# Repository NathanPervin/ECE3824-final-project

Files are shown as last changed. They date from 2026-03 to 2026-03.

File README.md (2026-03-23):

# CO2 Monitor
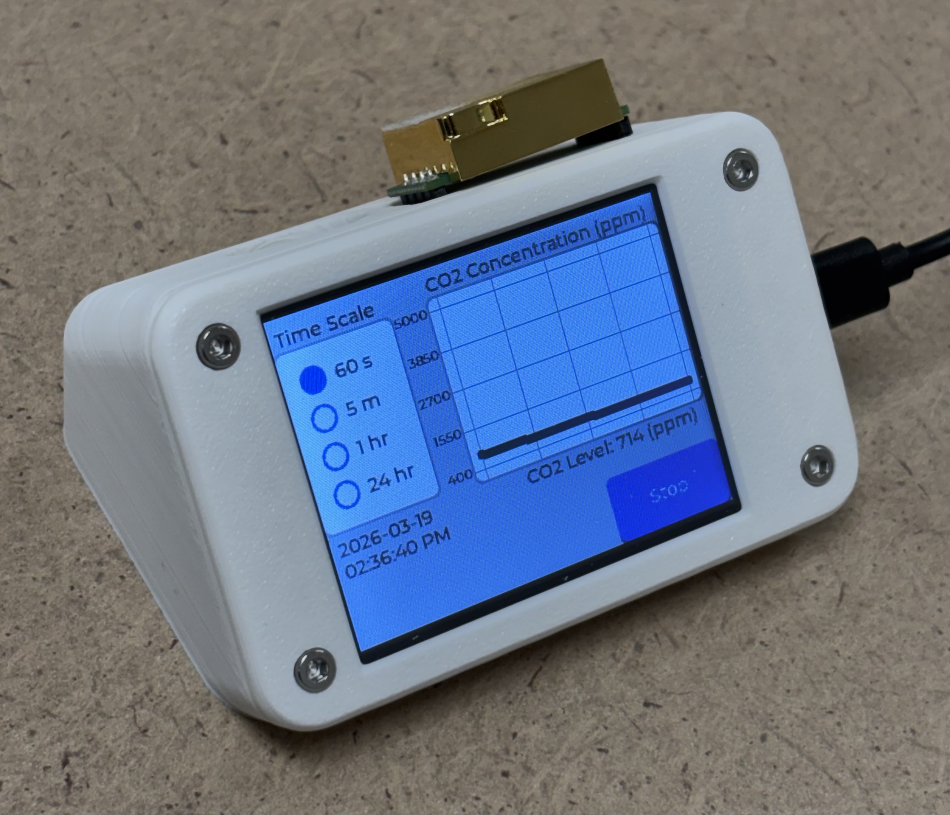
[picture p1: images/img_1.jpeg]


### Description
An ESP-32 device that monitors the CO2 level in the room and sends the infomation to a database in the cloud. A website will display the data.

### Impact
[Studies](https://www.sciencedirect.com/science/article/pii/S036013232300358X) have shown that short-term exposure to high levels of CO2 can reduce cognitive performance and negatively impact learning. Therefore, it is important to be ensure that CO2 levels remain low in an academic setting.

### Components
MH-Z19C CO2 Sensor ([more info](https://www.winsen-sensor.com/d/files/infrared-gas-sensor/mh-z19c-pins-type-co2-manual-ver1_0.pdf)) \
[by EC Buying](https://www.amazon.com/EC-Buying-Monitoring-Concentration-Detection/dp/B0CRKH5XVX)

ESP32 Cheap Yellow Display ([more info](https://www.lcdwiki.com/2.8inch_ESP32-32E_Display))\
[by Hosyond](https://www.amazon.com/gp/product/B0D92C9MMH)

3.7V LiPo Battery\
[by MakerHawk](https://www.amazon.com/gp/aw/d/B0D7MC714N)

### Features
* Screen automatically sleeps after 5 minutes of inactivity
* 1100 mAh battery with charging via the USB-C port (~6hr wireless battery life)
* Zero the CO2 sensor to 400 ppm by depressing the button for 7 seconds (only do this when outdoors)

### Dependencies
* Django for web app, API endpoint, and PostgreSQL database
* LVGL for ESP-32 GUI
* TFT_eSPI
* XPT2046_Touchscreen

### Web Hosting
* AWS EC2 for Django application
* AWS RDS for PostgreSQL

### Data Collection and Upload
Data will be in the following format:
```JSON
{"mode":"ambient","building":"COE","room_number":306,"unix_timestamp":1678886400,"CO2_ppm":750}
{"mode":"ambient","building":"COE","room_number":306,"unix_timestamp":1678886401,"CO2_ppm":760}
```
Samples will be taken every 1 second. The timestamp will be updated after each data POST request to keep the timestamps accurate over long periods of time. POST requests will be made every 5 minutes to reduce power usage and live data is already displayed on the CYD. A PostgreSQL database hosted in the cloud will be used to store the data.

### Pinout
| Pin | Use |
|-----|-----|
| IO35 | PWM for CO2 Sensor |
| 5V (UART PORT) | Vin for CO2 Sensor |
| GND | GND for CO2 Sensor |
| GND | GND for button -> CO2 Sensor HD Pin |

### CAD
Modified [ghfisanotti's CYD Case on Thingiverse](https://www.thingiverse.com/thing:7047135), licensed under CC BY-SA 3.0. See CAD folder in this repo for the STL and STEP files. 

### Required Parts and Assembly
* 1x ESP-32 CYD
* 1x MH-Z19C CO2 Sensor
* 1x 3.7 V Lipo w/ JST 1.25mm connector *optional
* 2x 1.25mm 4-pin JST to Dupont connectors
* 1x CYD_LID (3D printed)
* 1x CYD_BASE (3D printed)
* 4x M3 heat-set inserts
* 4x M3x8 bolts
* 1x [push button](https://www.amazon.com/Waterproof-Momentary-Button-Switch-Colors/dp/B07F24Y1TB) *optional, for zeroing the sensor
* 1x 5-pin female pin header *optional, for securing the sensor to the base

The 5-pin female pin header is secured by melting the plastic around it with a soldering iron. On the female pin header that the MH-Z19C's HD pin will plug into, solder a wire (this will connect to one pin of the button). Connect the other pin of the button to a GND pin on the CYD.

### Stretch Goals
* Dark Mode for ESP-32
* Handle http failure codes: handle extending batch size for POST failure, reattempt POST some number of times before clearing the buffer to avoid overflow. 
* ESP-32 timezone configuration for displayed time
* add more than just wifi connection errors to esp-32 error handler

### Data Visualization
* User should be able to search by building, room number, time (range, date)
* User should be able to see the most recent data in a plot (with the number of minutes since last data upload)
* User should be able to modify the parameters of the displayed plot (ex. time scale)
* Code should include a room score so the user can search for the rooms with the highest and lowest CO2 levels
* user should be able to search for a building and see all room numbers listed and the number of sessions/ ambients for each, also the room scores should be visable here.
* user should be able to select a room number from the above list and see a list of sessions, selecting one brings up a plot with the data.

### Temporary development notes
#### Tutorials 
[GUI Configs](https://randomnerdtutorials.com/lvgl-cheap-yellow-display-esp32-2432s028r) \
[LVGL Widgets Docs](https://docs.lvgl.io/master/widgets/)

#### TODO
* stop button logs whatever data is cached and goes back to start screen
* display elapsed time also if in session mode
* set building and room number to 'debug' when value is not given (so it can be filtered out in database)
* check if the plot can just be refreshed without loading new buffer (with flag for refresh without time scale change)
* first 1-2 mins make plot line blue to indicate sensor warming up
* make sure not to call get unix time twice when logging data (use same reference for displaying the time and logging data)
* stop button should disconnect wifi
* dont get unix time from load_buffers every time it is called, get unix time when making a post, increment the existing unix time from load_buffers instead since it is called once per second (create new variable for increment amount in case data logging interval changes in future)
* maybe use a finer time scale than seconds
* create stylus holder loop next to usb-c port due to issue where the stylus can fall into the enclosure
* write documentation for buffer max sizes for secrets.h.example, include the max building and room sizes, max JSON lines, etc.
* check if its currently on by checking if the most recent timestamp is less than 5 mins, indicate that its the live data and not the most recent session/ambient
* chart on first page should default to the most recent session, searching for a second would replace that plot with the data the user wants

* sessions in dashboard/views.py only returns UTC time regardless of user's timezone

minor bug fixes
* duration shows 4mins 59 secs instead of 5 mins for single upload (check if this error will accumulate)

#### Info
EC2 instance Django server running on:
http://107.23.179.9:8000/

Create virtual environment
```bash
python -m venv venv
```

activate the environment
```bash
source venv/bin/activate
```

Install PostgreSQL
```bash
sudo apt install postgresql postgresql-contrib
```

```bash
pip install -r requirements.txt
```

Create a .env inside of CO2 Dashboard, add the secrets, then run the server:
```bash
nohup python3 manage.py runserver 0.0.0.0:8000 &
```

Add the ip address to the allowed host list in setting.py.

stop old application
```bash
pkill -f "manage.py runserver"
```

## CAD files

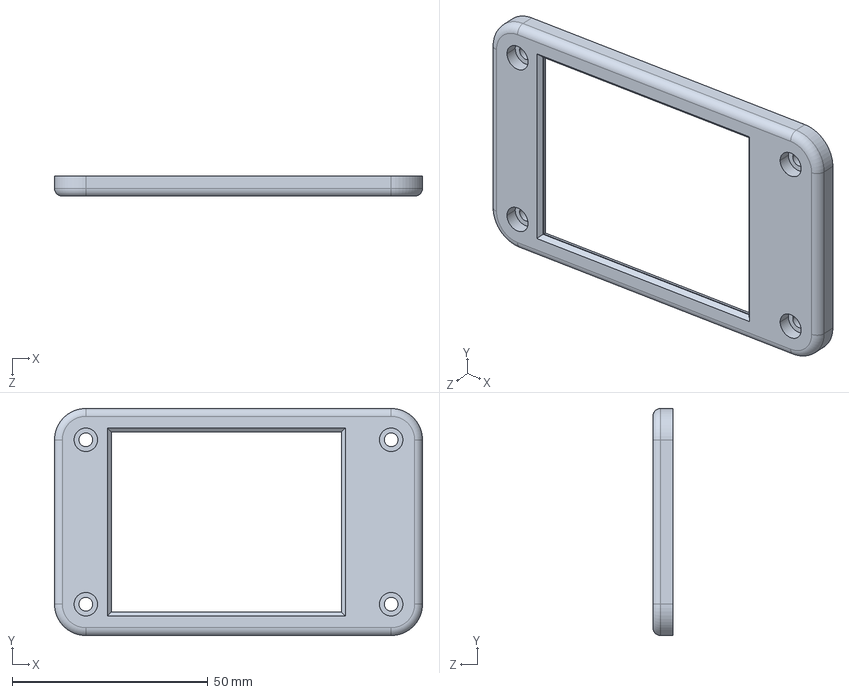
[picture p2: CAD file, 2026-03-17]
CAD/CYD_LID.STEP
94.0 x 58.0 x 5.20 mm

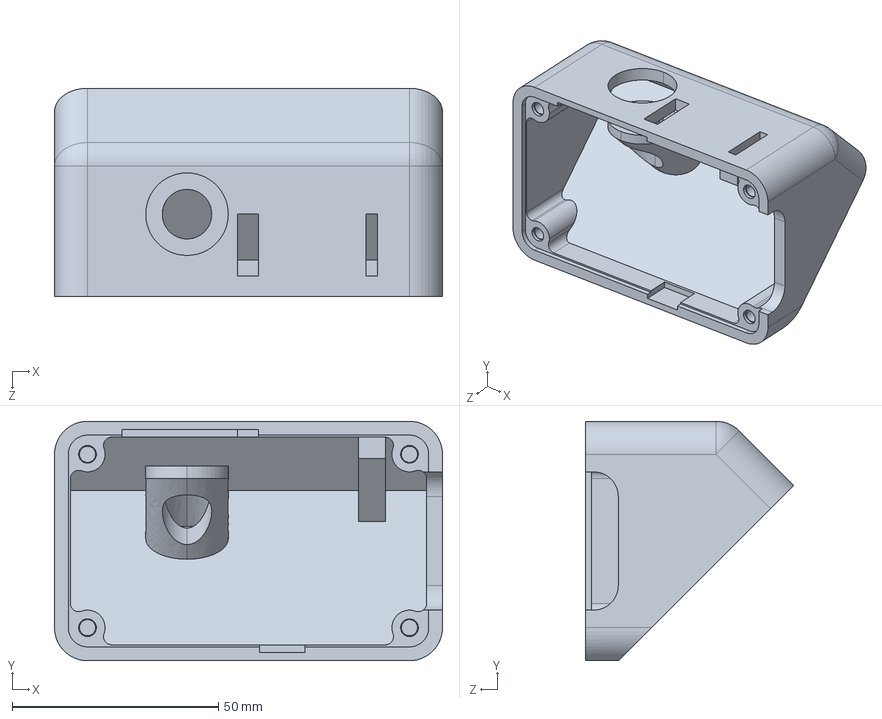
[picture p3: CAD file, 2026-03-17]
CAD/CYD_BASE.STEP
94.0 x 58.0 x 50.5 mm

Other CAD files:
CAD/CYD_BASE.STL
CAD/CYD_LID.STL

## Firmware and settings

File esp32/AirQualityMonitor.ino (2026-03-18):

// GUI:
// Configuration files and base code from: https://randomnerdtutorials.com/lvgl-cheap-yellow-display-esp32-2432s028r
// LVGL documentation: https://docs.lvgl.io/

// includes for GUI
#include <lvgl.h>
#include <TFT_eSPI.h>
#include <XPT2046_Touchscreen.h>

// includes for WIFI
#include <WiFi.h>
#include <time.h>
#include <secrets.h>

/*
    GUI Variables
*/
// Touchscreen pins
#define XPT2046_IRQ 36   // T_IRQ
#define XPT2046_MOSI 32  // T_DIN
#define XPT2046_MISO 39  // T_OUT
#define XPT2046_CLK 25   // T_CLK
#define XPT2046_CS 33    // T_CS

#define TFT_BL 21 // backlight

SPIClass touchscreenSPI = SPIClass(VSPI);
XPT2046_Touchscreen touchscreen(XPT2046_CS, XPT2046_IRQ);

#define SCREEN_WIDTH 240
#define SCREEN_HEIGHT 320

// Touchscreen coordinates: (x, y) and pressure (z)
int x, y, z;

#define DRAW_BUF_SIZE (SCREEN_WIDTH * SCREEN_HEIGHT / 10 * (LV_COLOR_DEPTH / 8))
uint32_t draw_buf[DRAW_BUF_SIZE / 4];

const char* top_text = "Air Quality Monitor";
const char* enter_building_text = "Building";
const char* enter_room_number_text = "Room Number";
const char* ambient_text = "Ambient";
const char* session_text = "Session";
const char* CO2_plot_title = "CO2 Concentration (ppm)";
const char* time_scale_text = "Time Scale";

bool is_ambient = true; // default value is to record as an ambient, if false, mode is session

static lv_obj_t* start_screen;
static lv_obj_t* recording_screen;

static lv_obj_t * ta1; // text area for the building input
static lv_obj_t * ta2; // text area for the room input

#define MAX_INPUT_TEXT_LENGTH 50
char building_text[MAX_INPUT_TEXT_LENGTH];
char room_text[MAX_INPUT_TEXT_LENGTH];

static lv_obj_t * chart;
static lv_chart_series_t * ser;

// the width of the x axis, in seconds 
static short int time_scale = 60; 

// determines how many point will be displayed at once,
const short int number_plot_points = 60; 
const short int CO2_plot_rate = 1000; // ms
static short int CO2_min = 400; // ppm
static short int CO2_max = 5000; // ppm

static lv_style_t style_radio;
static lv_style_t style_radio_chk;

const char* time_scales[] = {
  "60 s",
  "5 m",
  "1 hr",
  "24 hr",
  NULL
};

typedef enum {
  t_60s,
  t_5mins,
  t_1hr,
  t_24hrs
} TimeScale;

TimeScale current_time_scale = t_60s;

const int screen_sleep_after_time = 300000; // ms, 5 mins

lv_obj_t * CO2_level_label;
char CO2_level_text[30];

lv_obj_t * time_label;
char time_text[32];

lv_obj_t * error_label;
char error_text[32];

/*
//  CO2 Sensor Variables
*/
#define CO2_PWM_PIN 35

volatile unsigned long previous_low_start = 0;  // us
volatile unsigned long previous_high_start = 0; //us
volatile unsigned long TL = 0; // us
volatile unsigned long TH = 0; // us

const short int CO2_log_rate = 1000; // ms

/*
    WIFI Variables
*/
const char* ntpServer = "pool.ntp.org";
const long gmtOffset_sec = -18000;   // EST
const int daylightOffset_sec = 3600;  // 1 hour for daylight saving
bool wifi_initialized = false;
//int last_wifi_init_attempt = 0; // seconds since last initialization attempt
//const int attempt_wifi_init_every = 120; // interval for time between wifi attempts to be initalized

unsigned long last_wifi_init_attempt = 0; // timestamp of last attempt
const unsigned long attempt_wifi_init_every = 120000; // 2 minutes in ms

/*
    System Variables
*/
// buffers that will store the last 60 points
// which are an average of the available time intervals
static int32_t buffer_60secs[number_plot_points];
static int32_t buffer_5min[number_plot_points];
static int32_t buffer_1hr[number_plot_points];
static int32_t buffer_24hrs[number_plot_points];

// store the index where the next value should be placed
int i_60secs = 0;
int i_5mins = 0;
int i_1hr = 0;
int i_24hrs = 0;

// variables to find the average CO2 ppm over an interval
float sum_last_5s_CO2 = 0;
float count_5s = 0;
float sum_last_60s_CO2 = 0;
float count_60s = 0;
float sum_last_1440s_CO2 = 0;
float count_1440s = 0;

const short int ppm_threshold = 2000; // CO2 ppm above this will make the plot line red
static float CO2_value = 0;

bool on_start_screen = false;
bool on_recording_screen = false;

/*
    CO2 Sensor Functions
*/
// Software interrupt on IO35 Change
void ARDUINO_ISR_ATTR read_PWM() {

  // Get level to determine if the ISR was triggered on rising on falling edge
  int level = digitalRead(CO2_PWM_PIN);

  // get the current microseconds since program start or last overflow
  unsigned long now = micros(); 

  // rising edge, the duration of the low time can be calculated by
  // subtracting the previous falling edge's time from the current time
  if (level == HIGH) {
    TL = now - previous_low_start;
    previous_high_start = now;
  } else { 
    // falling edge, the duration of the high time preceding this can be found by 
    // subtracting the previous rising edge's time from the current time
    TH = now - previous_high_start;
    previous_low_start = now;
  }
}

/*
    WIFI Functions
*/
void initialize_wifi() {
  Serial.printf("Connecting to Wi-Fi %s ...\n", WIFI_SSID);

  // SSID and password must be inside of secrets.h
  WiFi.begin(WIFI_SSID, WIFI_PASSWORD);

  // try to connect to the wifi
  int attempts = 0;
  while (WiFi.status() != WL_CONNECTED && attempts < 20) {
    delay(500);
    Serial.print(".");
    attempts++;
  }

  if(WiFi.status() != WL_CONNECTED){
    Serial.println("\nFailed to connect to Wi-Fi");
    wifi_initialized = false;
    error_handler();
    return;
  } 
  else {
    wifi_initialized = true;
    error_handler();
  }

  Serial.println("\nWi-Fi connected!");
  Serial.print("IP address: ");
  Serial.println(WiFi.localIP());

  // Initialize NTP
  configTime(gmtOffset_sec, daylightOffset_sec, ntpServer);
}

bool handle_wifi_reinitialization() {
  if (!wifi_initialized) {
    if (millis() - last_wifi_init_attempt >= attempt_wifi_init_every) {
      initialize_wifi();
      last_wifi_init_attempt = millis(); // reset timestamp
      return wifi_initialized;
    }
    else {
      return false;
    }
  }
  return true;
}

time_t get_unix_time() {

  if (!handle_wifi_reinitialization()) return -1;

  Serial.println("Getting time from NTP server...");
  time_t now = time(nullptr);
  int retry = 0;
  const int retry_count = 10;

  // ensure unix time is valid, otherwise try again
  while (now < 1000000000 && retry < retry_count) { 
    delay(500);
    Serial.print(".");
    now = time(nullptr);
    retry++;
  }

  if(now < 1000000000) return 0;
  return now;
}

/*
    System Functions
*/
// called each time a CO2 value is collected (every 1 second),
// values get averaged and stored in all buffers to allow for
// past data to be displayed for new timescale 
void load_buffers(float CO2_ppm) {

  // load buffer, get next index
  int32_t val = (int32_t)CO2_ppm;
  buffer_60secs[i_60secs] = val;
  i_60secs = (i_60secs + 1) % number_plot_points; // index of 60 loops back to 0

  // avoid duplicate plot updates
  if (current_time_scale == t_60s) {
    update_plot();
  }

  // calculate sums and advance counters
  sum_last_5s_CO2 += CO2_ppm;
  count_5s++;
  sum_last_60s_CO2 += CO2_ppm;
  count_60s++;
  sum_last_1440s_CO2 += CO2_ppm;
  count_1440s++;

  // push the last 5 second average into the 5 minute buffer 
  if(count_5s >= 5) {

    int32_t avg = (int32_t)(sum_last_5s_CO2 / count_5s);

    // load buffer, get next index 
    buffer_5min[i_5mins] = avg;
    i_5mins = (i_5mins + 1) % number_plot_points;

    sum_last_5s_CO2 = 0;
    count_5s = 0;
    update_plot();
  }

  // push the last 60 second average into the 1 hour buffer 
  if(count_60s >= 60) {

    int32_t avg = (int32_t)(sum_last_60s_CO2 / count_60s);

    // load buffer, get next index 
    buffer_1hr[i_1hr] = avg;
    i_1hr = (i_1hr + 1) % number_plot_points;

    sum_last_60s_CO2 = 0;
    count_60s = 0;
    update_plot();
  }

  // push the last 1440 second average into the 24 hour buffer 
  if(count_1440s >= 1440) {

    int32_t avg = (int32_t)(sum_last_1440s_CO2 / count_1440s);

    // load buffer, get next index 
    buffer_24hrs[i_24hrs] = avg;
    i_24hrs = (i_24hrs + 1) % number_plot_points;

    sum_last_1440s_CO2 = 0;
    count_1440s = 0;
    update_plot();
  }

}

// clears all buffers and related variables
// used when user creates a new recording session
void clear_buffers() {

  // initialize the buffers so that the plot will be empty on start
  for(int i = 0; i < number_plot_points; i++) {
    buffer_60secs[i] = LV_CHART_POINT_NONE;
    buffer_5min[i] = LV_CHART_POINT_NONE;
    buffer_1hr[i] = LV_CHART_POINT_NONE;
    buffer_24hrs[i] = LV_CHART_POINT_NONE;
  }

  i_60secs = 0;
  i_5mins = 0;
  i_1hr = 0;
  i_24hrs = 0;

  sum_last_5s_CO2 = 0;
  count_5s = 0;
  sum_last_60s_CO2 = 0;
  count_60s = 0;
  sum_last_1440s_CO2 = 0;
  count_1440s = 0;

}

// Gets the building and room number text from the text areas, checks that the they are valid
bool get_location() {
  const char* building_text_const = lv_textarea_get_text(ta1); 
  const char* room_text_const = lv_textarea_get_text(ta2); 

  if (strlen(building_text_const) >= MAX_INPUT_TEXT_LENGTH) {
    Serial.println("Error: Building name too long!");
    return false;
  }
  if (strlen(room_text_const) >= MAX_INPUT_TEXT_LENGTH) {
    Serial.println("Error: Room number too long!");
    return false;
  }

  strncpy(building_text, building_text_const, MAX_INPUT_TEXT_LENGTH - 1);
  building_text[MAX_INPUT_TEXT_LENGTH - 1] = '\0';
  strncpy(room_text, room_text_const, MAX_INPUT_TEXT_LENGTH - 1);
  room_text[MAX_INPUT_TEXT_LENGTH - 1] = '\0';
  return true;
}

// called to update the error text, handles displaying multiple errors
static void error_handler() {
  if (!wifi_initialized) {
    snprintf(error_text, sizeof(error_text), "%s", "Failed to connect to Wi-Fi");
  }
  else { // TMP, save old errors later
    snprintf(error_text, sizeof(error_text), "%s", "");
  }
}

// Get the Touchscreen data
void touchscreen_read(lv_indev_t * indev, lv_indev_data_t * data) {

  // Checks if Touchscreen was touched, and prints X, Y and Pressure (Z)
  if(touchscreen.tirqTouched() && touchscreen.touched()) {
    
    // turn on backlight to make screen visable
    digitalWrite(TFT_BL, HIGH);

    // Get Touchscreen points
    TS_Point p = touchscreen.getPoint();

    // Calibrate Touchscreen points with map function to the correct width and height
    x = map(p.x, 200, 3700, 1, SCREEN_WIDTH);
    y = map(p.y, 240, 3800, 1, SCREEN_HEIGHT);
    z = p.z;

    data->state = LV_INDEV_STATE_PRESSED;

    // Set the coordinates
    data->point.x = x;
    data->point.y = y;
  }
  else {
    data->state = LV_INDEV_STATE_RELEASED;
  }
}

static void ta_event_cb(lv_event_t * e)
{
  lv_event_code_t code = lv_event_get_code(e);
  lv_obj_t * ta = lv_event_get_target_obj(e);
  lv_obj_t * kb = (lv_obj_t *)lv_event_get_user_data(e);
  if(code == LV_EVENT_FOCUSED) {
      lv_keyboard_set_textarea(kb, ta);
      lv_obj_remove_flag(kb, LV_OBJ_FLAG_HIDDEN);
  }

  if(code == LV_EVENT_DEFOCUSED) {
      lv_keyboard_set_textarea(kb, NULL);
      lv_obj_add_flag(kb, LV_OBJ_FLAG_HIDDEN);
  }
}

// Creates text centered at the top of the screen
void lv_top_text(lv_obj_t* screen) {

  lv_obj_t * text_label = lv_label_create(screen);
  lv_label_set_long_mode(text_label, LV_LABEL_LONG_WRAP);    
  lv_label_set_text(text_label, top_text);
  lv_obj_set_width(text_label, 150);    // width of the text (wraps if text is longer than the input number)
  lv_obj_set_style_text_align(text_label, LV_TEXT_ALIGN_CENTER, 0);
  lv_obj_align(text_label, LV_ALIGN_CENTER, 0, -105);
}

// Creates the keyboard when a text area is selected
// Allows the user to enter a building and room number
void lv_keyboard(lv_obj_t* screen) {
  // Create a keyboard, automatically displays when a text box is clicked on
  lv_obj_t * kb = lv_keyboard_create(screen);

  // Enter Building Text (Above the text box)
  lv_obj_t * building_text_label = lv_label_create(screen);
  lv_label_set_long_mode(building_text_label, LV_LABEL_LONG_WRAP);    // Breaks the long lines
  lv_label_set_text(building_text_label, enter_building_text);
  lv_obj_set_width(building_text_label, 150);    // Set smaller width to make the lines wrap
  lv_obj_set_style_text_align(building_text_label, LV_TEXT_ALIGN_LEFT, 0);
  lv_obj_align(building_text_label, LV_ALIGN_TOP_LEFT, 45, 30);

  // text area for the building entry. The keyboard will write here
  ta1 = lv_textarea_create(screen);
  lv_obj_align(ta1, LV_ALIGN_TOP_LEFT, 10, 50);
  lv_obj_add_event_cb(ta1, ta_event_cb, LV_EVENT_ALL, kb);
  lv_textarea_set_placeholder_text(ta1, "COE");
  lv_obj_set_size(ta1, 140, 35);
  
  // Room Number Text (Above the text box)
  lv_obj_t * room_number_text_label = lv_label_create(screen);
  lv_label_set_long_mode(room_number_text_label, LV_LABEL_LONG_WRAP);    // Breaks the long lines
  lv_label_set_text(room_number_text_label, enter_room_number_text);
  lv_obj_set_width(room_number_text_label, 200);    // Set smaller width to make the lines wrap
  lv_obj_set_style_text_align(room_number_text_label, LV_TEXT_ALIGN_LEFT, 0);
  lv_obj_align(room_number_text_label, LV_ALIGN_TOP_LEFT, 185, 30);

  // text area for the room number, the keyboard will write here
  ta2 = lv_textarea_create(screen);
  lv_obj_align(ta2, LV_ALIGN_TOP_RIGHT, -10, 50);
  lv_obj_add_event_cb(ta2, ta_event_cb, LV_EVENT_ALL, kb);
  lv_textarea_set_placeholder_text(ta2, "306");
  lv_obj_set_size(ta2, 140, 35);

  lv_keyboard_set_textarea(kb, ta1);

}

// Called when the Ambient/Session switch is toggled,
// used for specifying the mode
static void switch_event_handler(lv_event_t * e) {
  lv_event_code_t code = lv_event_get_code(e);
  lv_obj_t * obj = lv_event_get_target_obj(e); 
  LV_UNUSED(obj);
  if(code == LV_EVENT_VALUE_CHANGED) {

    // if its set to "ON", its set to a session, otherwise its set to ambient   
    is_ambient = !(lv_obj_has_state(obj, LV_STATE_CHECKED)); 
  }
}
// Creates the ambient/session toggle switch
// located on the left, below the text areas
void lv_switch(lv_obj_t* screen) {

  // Ambient Text (to the left of the switch)
  lv_obj_t * ambient_text_label = lv_label_create(screen);
  lv_label_set_long_mode(ambient_text_label, LV_LABEL_LONG_WRAP);    // Breaks the long lines
  lv_label_set_text(ambient_text_label, ambient_text);
  lv_obj_set_width(ambient_text_label, 200);    // Set smaller width to make the lines wrap
  lv_obj_set_style_text_align(ambient_text_label, LV_TEXT_ALIGN_LEFT, 0);
  lv_obj_align(ambient_text_label, LV_ALIGN_TOP_LEFT, 10, 95);

  // Session Text (to the right of the switch)
  lv_obj_t * session_text_label = lv_label_create(screen);
  lv_label_set_long_mode(session_text_label, LV_LABEL_LONG_WRAP);    // Breaks the long lines
  lv_label_set_text(session_text_label, session_text);
  lv_obj_set_width(session_text_label, 200);    // Set smaller width to make the lines wrap
  lv_obj_set_style_text_align(session_text_label, LV_TEXT_ALIGN_LEFT, 0);
  lv_obj_align(session_text_label, LV_ALIGN_TOP_LEFT, 135, 95);

  // toggle switch (centered between texts)
  lv_obj_t * sw;
  sw = lv_switch_create(screen);
  lv_obj_align(sw, LV_ALIGN_TOP_LEFT, 80, 90);
  lv_obj_add_event_cb(sw, switch_event_handler, LV_EVENT_ALL, NULL);
  lv_obj_add_flag(sw, LV_OBJ_FLAG_EVENT_BUBBLE);

}

// Called when the Start button is pressed
static void start_button_event(lv_event_t * e) {
  lv_event_code_t code = lv_event_get_code(e);
  if(code == LV_EVENT_CLICKED) {

    // if the location text is valid, advance to the recording screen
    if (!get_location()) return;
    lv_scr_load(recording_screen);
    on_start_screen = false;
    on_recording_screen = true;
    clear_buffers();
  }
}

// Creates the start button
void lv_start_button(lv_obj_t* screen) {

  // Button, located to the right of toggle switch
  lv_obj_t * label;
  lv_obj_t * btn1 = lv_button_create(screen);
  lv_obj_add_event_cb(btn1, start_button_event, LV_EVENT_ALL, NULL);
  lv_obj_align(btn1, LV_ALIGN_TOP_LEFT, 245, 85);
  lv_obj_remove_flag(btn1, LV_OBJ_FLAG_PRESS_LOCK);
  
  // Text inside the button
  label = lv_label_create(btn1);
  lv_label_set_text(label, "Start");
  lv_obj_center(label);

}

// Creates the chart for CO2 values
void lv_chart(lv_obj_t* screen) {
  chart = lv_chart_create(screen);
  lv_obj_set_size(chart, 200, 140); // 200x140 pixels
  lv_obj_align(chart, LV_ALIGN_CENTER, 60, -30);

  lv_obj_refresh_ext_draw_size(chart);

  ser = lv_chart_add_series(chart, lv_palette_main(LV_PALETTE_RED), LV_CHART_AXIS_PRIMARY_Y);
  lv_chart_set_axis_range(chart, LV_CHART_AXIS_PRIMARY_Y, CO2_min, CO2_max);
  lv_chart_set_axis_range(chart, LV_CHART_AXIS_PRIMARY_X, 0, time_scale);
  lv_chart_set_point_count(chart, number_plot_points);
  lv_chart_set_update_mode(chart, LV_CHART_UPDATE_MODE_SHIFT);
  lv_chart_set_div_line_count(chart, 5, 5); // (...,5 horizontal lines, 5 vertical lines)

  // Text for the plot title
  lv_obj_t * label = lv_label_create(screen);
  lv_label_set_text(label, CO2_plot_title);
  lv_obj_align_to(label, chart, LV_ALIGN_OUT_TOP_MID, -2, 0);

  // Text for the top (max) CO2 axis label
  lv_obj_t * y_label_top = lv_label_create(screen);
  lv_label_set_text_fmt(y_label_top, "%d", CO2_max);
  lv_obj_set_style_text_font(y_label_top, &lv_font_montserrat_10, 0);
  lv_obj_align_to(y_label_top, chart, LV_ALIGN_OUT_LEFT_TOP, 0, 5);

  // Text for between the top and middle CO2 axis label 
  lv_obj_t * y_label_1 = lv_label_create(screen);
  lv_label_set_text_fmt(y_label_1, "%d", CO2_min + (CO2_max - CO2_min)*3/4);
  lv_obj_set_style_text_font(y_label_1, &lv_font_montserrat_10, 0);
  lv_obj_align_to(y_label_1, chart, LV_ALIGN_OUT_LEFT_TOP, 0, lv_obj_get_height(chart)/4);

  // Text for the middle CO2 axis label
  lv_obj_t * y_label_mid = lv_label_create(screen);
  lv_label_set_text_fmt(y_label_mid, "%d", (CO2_min + CO2_max)/2);
  lv_obj_set_style_text_font(y_label_mid, &lv_font_montserrat_10, 0);
  lv_obj_align_to(y_label_mid, chart, LV_ALIGN_OUT_LEFT_MID, 0, 0);

  // Text for between the middle and bottom CO2 axis label 
  lv_obj_t * y_label_3 = lv_label_create(screen);
  lv_label_set_text_fmt(y_label_3, "%d", CO2_min + (CO2_max - CO2_min)*1/4);
  lv_obj_set_style_text_font(y_label_3, &lv_font_montserrat_10, 0);
  lv_obj_align_to(y_label_3, chart, LV_ALIGN_OUT_LEFT_BOTTOM, 0, -lv_obj_get_height(chart)/4);

  // Text for the bottom (min) CO2 axis label
  lv_obj_t * y_label_bottom = lv_label_create(screen);
  lv_label_set_text_fmt(y_label_bottom, "%d", CO2_min);
  lv_obj_set_style_text_font(y_label_bottom, &lv_font_montserrat_10, 0);
  lv_obj_align_to(y_label_bottom, chart, LV_ALIGN_OUT_LEFT_BOTTOM, 0, -5);

}

// Called when the user selects a radio button option
static void event_radio_button(lv_event_t * e) {
  lv_obj_t * obj = lv_event_get_target_obj(e);

  // check that the checkbox is checked (radio button is selected)
  // since this event is called twice for the unchecking of the previous
  // option and the checking of a new option
  if(!lv_obj_has_state(obj, LV_STATE_CHECKED)) {
    return;
  }

  // determine which timescale the user has selected:
  // 60 seconds timescale
  if (strcmp(lv_checkbox_get_text(obj), time_scales[0]) == 0) {
    current_time_scale = t_60s;
  }
  else if (strcmp(lv_checkbox_get_text(obj), time_scales[1]) == 0) {
    current_time_scale = t_5mins;
  }
  else if (strcmp(lv_checkbox_get_text(obj), time_scales[2]) == 0) {
    current_time_scale = t_1hr;
  }
  else if (strcmp(lv_checkbox_get_text(obj), time_scales[3]) == 0) {
    current_time_scale = t_24hrs;
  }
  else {
    Serial.print("Unable to resolve time scale from radio box selection!");
  }

  update_plot();
}
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
void loop() {
  lv_task_handler();  // let the GUI do its work
  lv_tick_inc(5);     // tell LVGL how much time has passed
  delay(5);           // let this time pass

  // CO2 sensor elapsed time
  static unsigned long previous_log_time = 0;
  unsigned long now = millis();

  // CO2 sensor ppm calculation and logging
  if (now - previous_log_time >= CO2_log_rate) { // update every 1 second
    previous_log_time = now;

    // TH + TL should sum to above 4000 us to prevent a divide
    // by zero or negative ppm (can occur while sensor is heating)
    if (TH + TL > 4000) {

      // Using formula from datasheet: Cppm = 5000 * (TH - 2) / (TH + TL - 4),
      // converted to microseconds
      float ppm = 5000.0 * (TH - 2000) / (TH + TL - 4000);
      ppm = constrain(ppm, 400, 5000); // the sensor's range is 400-5000 ppm
      // Serial.print("CO2: ");
      // Serial.print(ppm);
      // Serial.println(" ppm");
      CO2_value = ppm;
      load_buffers(ppm);
    } else {
      Serial.println("Invalid PWM Received");
    }
  }

  // Turns the backlight off after some time of inactivity
  if(lv_disp_get_inactive_time(NULL) > screen_sleep_after_time) {
    digitalWrite(TFT_BL, LOW);
  }

}

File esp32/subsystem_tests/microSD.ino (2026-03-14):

// Code primarily from https://github.com/witnessmenow/ESP32-Cheap-Yellow-Display/blob/main/Examples/Basics/3-SDCardTest/3-SDCardTest.ino
// This code simply prints an example of 15 JSON Lines to a file called 'log.txt' on the microSD card inserted to the ESP32 CYD

#include "FS.h"
#include "SD.h"
#include "SPI.h"

const char* filename = "/log.txt";

/*
  Usage: writeFile(SD, "/hello.txt", "Hello ");
*/
bool writeFile(fs::FS &fs, const char * path, const char * message) {
  Serial.printf("Writing file: %s\n", path);

  File file = fs.open(path, FILE_WRITE);
  if (!file) {
    Serial.println("Failed to open file for writing");
    return false;
  }
  if (file.print(message)) {
    Serial.println("File written");
  } else {
    Serial.println("Write failed");
  }
  file.close();
  return true;
}

/*
  Usage: appendFile(SD, "/hello.txt", "World!\n");
*/
void appendFile(fs::FS &fs, const char * path, const char * message) {
  Serial.printf("Appending to file: %s\n", path);

  File file = fs.open(path, FILE_APPEND);
  if (!file) {
    Serial.println("Failed to open file for appending");  
    if (!writeFile(SD, filename, "")) {
      return;
    }
    file = fs.open(path, FILE_APPEND);
  }
  if (file.print(message)) {
    Serial.println("Message appended");
  } else {
    Serial.println("Append failed");
  }
  file.close();
}

/*
  Usage: deleteFile(SD, "/foo.txt");
*/
void deleteFile(fs::FS &fs, const char * path) {
  Serial.printf("Deleting file: %s\n", path);
  if (fs.remove(path)) {
    Serial.println("File deleted");
  } else {
    Serial.println("Delete failed");
  }
}

void readFile(fs::FS &fs, const char * path) {
  Serial.printf("Reading file: %s\n", path);

  File file = fs.open(path);
  if (!file) {
    Serial.println("Failed to open file for reading");
    return;
  }

  Serial.print("Read from file: ");
  while (file.available()) {
    Serial.write(file.read());
  }
  file.close();
}

void setup() {
  Serial.begin(115200);

  SPIClass spi = SPIClass(VSPI);

  if (!SD.begin(SS, spi, 80000000)) {
    Serial.println("Card Mount Failed");
    return;
  }
  uint8_t cardType = SD.cardType();

  if (cardType == CARD_NONE) {
    Serial.println("No SD card attached");
    return;
  }

  static short int i = 0;

  char* text = "{\"mode\":\"ambient\",\"building\":\"COE\",\"room_number\":306,\"unix_timestamp\":1678886400,\"temperature\":22.5}\n";
  for (i; i < 15; i++) {
    appendFile(SD, filename, text);
  }
  //deleteFile(SD, filename);

}

void loop() {

}

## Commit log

2026-03-14 created CO2 sensor code
2026-03-15 Added plotting using CO2 sensor data
2026-03-15 Rotated screen to properly work with a case
2026-03-16 Added STL files
    [CYD_BASE.stl, CYD_LID.stl]
2026-03-17 updated CAD models, added STEP files
    [CYD_BASE.STEP, CYD_BASE.STL, CYD_BASE.stl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]
2026-03-17 Added CO2 level number, time, and error labels to recording screen
    [AirQualityMonitor.ino]
2026-03-19 changed esp32 file structure
2026-03-21 cleaned formatting and code comments in esp32 code
